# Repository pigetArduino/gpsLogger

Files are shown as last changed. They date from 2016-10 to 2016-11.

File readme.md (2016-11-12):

GPS Logger
----------

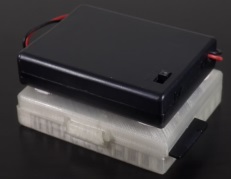
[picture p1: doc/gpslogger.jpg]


[Version française / French version](https://github.com/pigetArduino/gpsLogger/blob/master/readme.fr.md)

Record gps coordinate in a csv file on an Micro card every 15 seconds (DAYHOURMINUTESSECOND.csv)   
[Example file](https://github.com/pigetArduino/gpsLogger/blob/master/doc/example.csv)

# Download link
http://gps.madnerd.org

# Videos / Instructables
* How to build it : https://www.youtube.com/watch?v=gYxDJqSLVxQ
* How to use it : https://www.youtube.com/watch?v=96iCh5vVnsw
* Instructables : http://www.instructables.com/id/Simple-GPS-Logger/

# How to convert the track

## Gpsies.com
* Go to http://gpsies.com
* Click on Create a track
* Import the csv file
* Or click on convert to get a gpx track file

## Viking
* Download it here : https://sourceforge.net/projects/viking/
* Go to file
* Retrieve
* Import file with GPS Babel
* Choose (at the end of the list) : universal csv with field structure in first line
* Add a map in layer
* Use Open Street Map (Mapnick) or Bing Aerial

# Buzzer
The buzzer will tell you if there is any issues with the gps/ micro sdcard
* Heavy sound : Wiring issues or no microsd 
* Soft repetitive sound : GPS is calibrating (can take up to 5 minutes)
* Melody : GPS is online
* Soft and short sound : GPS coordinates saved to sd  

# Components
Use theses keyword to find the components
* Gps module ublox Aircraft model mwc: 8€
* Micro sd card 2go (w/ micro sd card adapter): 4€
* Batteries holder 4AAA on/off : 1€ 
* Arduino mini pro 3.3V : 1,50€
* Passive buzzer 3v:  1€  
* Total : 15.50€   

We are using a micro sd card adapter as a micro sdcard reader but you can also use a micro sd card reader module for this.

# Tools
* FTDI basic breakout usb ttl 3.3 : 6.23€
* Cable 30awg  8-color: 5.37€
 
# Software needed:
  * Arduino (Programmation): http://arduino.madnerd.org
  * Cura (3D printing): https://ultimaker.com/en/products/cura-software

# 3D models
[See 3D models](https://github.com/pigetArduino/gpsLogger/blob/master/3D/)
```
Tested on Ultimaker 2 GO with PLA
To improve solidity print A in solid
A Infill: Solid
B Infill: Light
```
* Author : Olivier Sarrailh   

# Wiring:
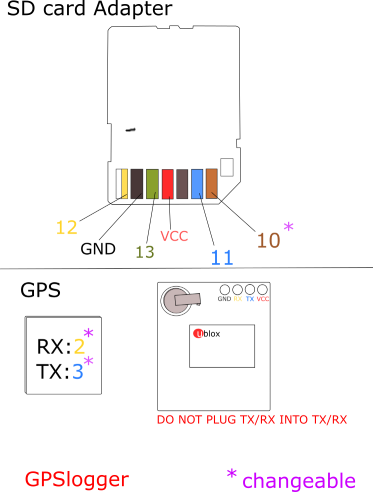
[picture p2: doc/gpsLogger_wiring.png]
Wiring GPS

##  Micro SD card Adapter
```
1 --> Not connected
2 --> 12
3 --> GND
4 --> 13
5 --> VCC
6 --> GND
7 --> 11
8 --> 10 (Chip select)
```
##  GPS
```
RX --> 2
TX --> 3

```
## Buzzer
```
+ ---> 9
```

# Batttery pack placement
As stated by bwh13 on instructables : 
You should avoid obstructing the antenna with the battery pack
```
Nice project.
Moving forward, consider placing your battery pack beneath your GPS module. The antenna works best with an unobstructed view of the sky
```

## Libraries
TinyGPS++ library : https://github.com/mikalhart/TinyGPSPlus

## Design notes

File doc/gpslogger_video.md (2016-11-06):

# Introduction

*   Today I will show you my gps Logger
*   This gps can be made for under 20 euros
*   And it pretty straightforward to use as there is only an on/off switch. 
*   When you power it up, the GPS will start to search for satellites for about 5 minutes
*   And then every 15gseconds, it will write your current position on a micro sd card
*   If you want to see how we made this GPS.
*   Watch the video in the description.
*   Let’s see what’s inside this case.

# Components

*   We have an arduino mini pro 3V
*   A microsd adapter
*   A gps with his antenna
*   A buzzer which will warm us if something doesn’t works
*   And finally a battery holder to power everything

Once you recorded a track on your microsd card you can display it on your computer using the website : gpsies.com or the software: viking

# Retrieve the GPS track

*   As an example we are going to use the track available in the documentation named : example.csv

## Text editor

*   First, Let’s open it with a text editor
*   As you can see the file is easy to understand and can be easily parse by others softwares
*   Let's see our track on a map and convert it as a gpx.

## Gpsies.com

*   The easiest way to do this, is to use the website gpsies.com
*   We just have to create a track and then import our file example.csv
*   We, now can see our gps track on a map
*   If you want to convert your track to read it with any GPS
*   Go to convert, browse, open your track
*   Click on Convert , and this will automatically download the gpx file

## Viking

*   You can also convert your track using the free software viking
*   Go to file, retrieve, import file with gps babel
*   Then open the csv file on the SD card of your GPSLogger
*   Finally go at the end of the list, to universal csv with field structure in first line
*   And press OK
*   This will display your track
*   You still need to add a map
*   We are going to use openstreetmap
*   You can use other maps like bing Aerial,
*   or even photos, scanned map…
*   The map will be download on your computer, so you won’t need a internet connection afterwhile
*   Click on OK
*   And that's it

# Ending

*   As always, all the link are in the description
*   Feel free to ask questions in the comments
*   And subscribe if you don’t want to miss my next projects!
*   Next time, we will see how to make a synth with a Raspberry Pi
*   Using samplerbox
*   I’ll try to make it as easy as possible
*   And show you my mod to use it as a drum machine
*   See you soon!

# Demo

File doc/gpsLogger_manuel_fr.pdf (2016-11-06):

# pigetArduino/gpsLogger

github.com/pigetArduino/gpsLogger/blob/master/readme.fr.md

pigetArduino

### Traceur GPS (GPS Logger)

Enregistre les coordonées GPS dans un fichier csv sur une carte micro sd toutes les 15 seconds (JOURHEUREMINUTESSECONDES.CSV) Fichier d'exemple (https://github.com/pigetArduino/gpsLogger/blob/master/doc/example.csv)

## Télécharger

http://gps.madnerd.org

## Comment convertir le parcours

### Gpsies.com

Aller sur http://gpsies.com
Cliquer sur Créer un parcours
Importer votre fichier csv
Ou Cliquer sur convertir pour avoir un fichier gpx

### Viking

Télécharger Viking ici : https://sourceforge.net/projects/viking/ Aller sur fichier
Récupérer
Import file with GPS Babel
Choosisez (à la fin de la liste) : Import with gps babel Ajouter une map dans couches
Utilisez Open Street Map (Mapnick) ou Bing Aerial

## Sound du Buzzer

Son fort: Erreur de câblage ou carte SD absente
Son calme, court et répétitif : Le GPS est en calibration (cela peut prendre jusqu'à 5 minutes) Mélodie : Le GPS est fonctionnel
Son calme, court , toutes les 15 secondes: Coordonées sauvegardées

## Composants

Utilisez ses mots-clés pour chercher les composants:

Gps module ublox Aircraft model mwc: 8€ Micro sd card 2go : 4€
Batteries holder 4AAA on/off : 1€ Arduino mini pro 3.3V : 1,50€
Passive buzzer 3v: 1€
Total : 15.50€

## Outils

FTDI basic breakout usb ttl 3.3 : 6.23€ Cable 30awg 8-color: 5.37€

## Logiciels:

Arduino (Programmation): http://arduino.madnerd.org
Cura (3D printing): https://ultimaker.com/en/products/cura-software

## Modèles 3D

Voir les modèles 3D (https://github.com/pigetArduino/gpsLogger/blob/master/3D/)

Testé sur une ultimaker 2 GO avec du PLA
Pour améliorer la solidité imprimer la partie A en solide.
A Infill: Solid
B Infill: Dense

Auteur : Olivier Sarrailh

## Câblage:

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
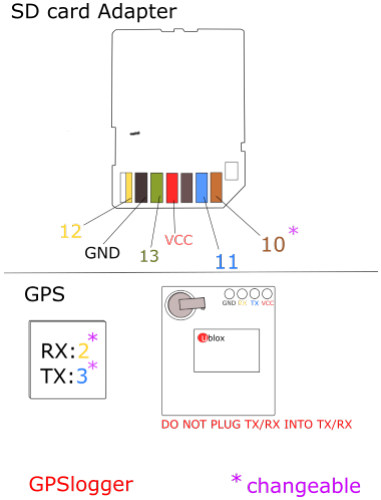
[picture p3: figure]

9 | 3/4

### Bibliothèques

TinyGPS++ library : https://github.com/mikalhart/TinyGPSPlus

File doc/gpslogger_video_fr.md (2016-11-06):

# Présentation

- Aujourd'hui on va voir un traceur GPS  
- Ce traceur GPS peut être fabriqué pour moins de 20 euros   
- Et il fonctionne vraiment simplement.   
- Il y a un bouton on/off, lorsque l'on appuie sur ON    
- Le gps va s'activer et une fois qu'il aura trouver les satellites
- Il va écrire toutes les 15 secondes sur une carte micro sd, votre position.
- Si vous voulez voir un peu comment ce GPS a été fabriqué.
- J'ai fait une vidéo très rapide où on voit toutes les étapes de fabrication 
de ce gps
- Allons voir un peu les composants à l'intérieur de ce boitier.   

# Composants
- A l'intérieur de notre boitier, 
- on a un arduino mini pro 3V
- Un adaptateur de microsd
- un gps ainsi que son antenne
- Et un buzzer qui va nous permettre de savoir si le gps fonctionne correctement
- Evidemment nous avons aussi un boitier de piles en bas qui va nous permettre d'alimenter notre arduino

Maintenant nous allons voir comment utiliser les données de notre GPS sur le site gpsies.com et directement avec le logiciel viking

# Récupérer le parcours GPS
* Comme exemple, nous allons prendre le fichier qui est fourni avec la documentation

## Editeur de texte
* example.csv, nous allons l'ouvrir avec un éditeur de texte standard
* Comme vous pouvez voir c'est un fichier qui est complètement lisible même avec le programme le plus basique possible
* Qu'est que'on va faire de ce fichier ?

## Gpsies.com
* Le plus simple si vous voulez le convertir où l'afficher c'est d'utiliser le site gpsies.com
* Sur ce site , on peut créer un parcours sur lequel on va importer notre fichier example.csv
* Et voilà! Nous avons notre tracé GPS sur une magnifique carte
* Alors, Si vous voulez juste convertir le fichier de façon à ce qu'il soit lisible par un GPS
* Il faut aller sur convertir, parcourir, ouvrir le fichier de la carte SD de votre GPS
* Convertir , et il vous donnera directement un fichier GPX

### Viking
* Si vous ne voulez pas passer par un site, vous pouvez utiliser le logiciel libre viking
* Pour cela, il faut aller dans fichier, récupérer, import file with gps babel
* Vous ouvrez votre fichier csv de la carte SD du GPSLogger
* Et après vous aller toute en bas à universal csv with field structure in first line
* Et vous faites valider
* Ca fait afficher toutes les points que le gps a récupéré
* Par défaut Viking n'utilise aucune carte
* Nous allons utiliser openstreetmap pour notre carte
* Vous pouvez utiliser d'autres cartes, voir même utiliser des images
* Vue que le logiciel est vraiment malléable là-dessus.
* Une fois que vous aurez télécharger la carte , vous n'aurez plus besoin d'internet normalement
* pour exploiter vos données.
* Reste plus qu'à valider
* Et voilà! Nous avons une jolie carte.

# Fin
* Comme d'habitude les liens sont dans la description
* N'hésitez pas à poster un commentaire si vous avez des questions
* Abonnez vous pour ne pas louper les prochaines vidéos
* La prochaine fois nous verrons comment faire un synthé avec un Raspberry Pi
* Non seulement on va faire un synthé mais aussi une boite à rythme
* Tout ça sans utiliser la moindre soudure
* Et sans passer par le terminal
* Juste en copier des trucs sur une carte SD 
* Et sur une clé USB.
* Allez à la prochaine

# Démonstration

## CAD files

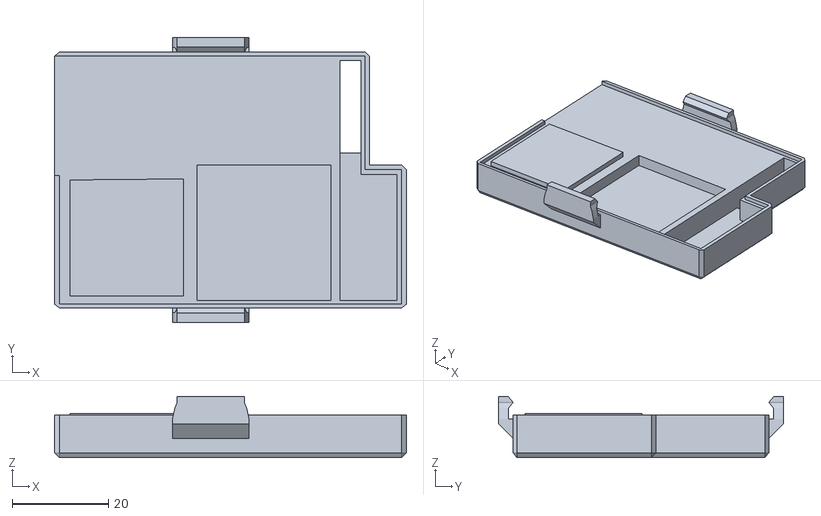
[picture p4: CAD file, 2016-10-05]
3D/gpslogger_B.stl
73.3 x 59.3 x 12.7

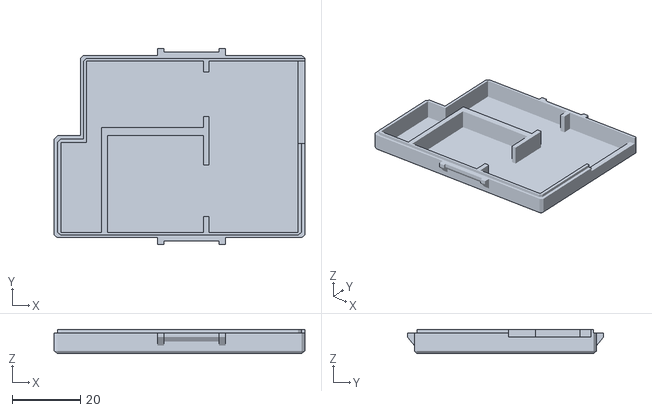
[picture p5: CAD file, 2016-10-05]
3D/gpslogger_A.stl
73.3 x 57.3 x 7.05

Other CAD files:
3D/gpslogger.blend

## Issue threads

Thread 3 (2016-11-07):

How do you get the recorded data off of the device if SD card is soldered?

slavik0329, 2016-11-07:
How do you get the recorded data off of the device if SD card is soldered?

maditnerd, 2016-11-09:
I realize I wasn't really clear about it, I solder a micro-sd card adapter not an sdcard.
I should probably update the doc to reflect this better.

slavik0329, 2016-11-11:
@maditnerd Yea, there is nothing in the docs at all about this. Thank you !

Closed 2016-11-11.

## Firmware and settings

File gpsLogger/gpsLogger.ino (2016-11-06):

/*
  Author: MadNerd.org
  Date:10/05/2016
  Licence: Mit

  Log speed/altitude/gps coordinate in a universal csv file (DAYHOURMINUTESSECOND.csv)
  You can convert .csv to a gpx with http://www.gpsies.com/convert.do
  You can also display it on viking https://sourceforge.net/projects/viking/
  You can reuse theses values in any spreedsheet software (LibreOffice/Excel...)

  Buzzer sound
  -- Heavy sound : GPS/SD card fatal error
  -- Soft repetitive sound : GPS is calibrating
  -- Soft and short sound : GPS coordinates saved to sd

  Components:
    Ublox GPS module (or compatible with tinygps++)
    Micro SD to SD card Adapter
    A buzzer
    An Arduino Pro Mini 3V
    Batteries

  Tools:
  ftdi 3V/5V programmer

  Wiring:
  SD card
  1 --> X
  2 --> 12
  3 --> GND
  4 --> 13
  5 --> VCC
  6 --> GND
  7 --> 11
  8 --> 10 (Chip select)

  GPS
  RX --> 2
  TX --> 3

  Buzzer --> 9

  You will need
    TinyGPS++ library

  Previous Readme
  This example uses software serial and the TinyGPS++ library by Mikal Hart
  Based on TinyGPSPlus/DeviceExample.ino by Mikal Hart
*/

/* Dependencies */
// GPS
#include <TinyGPS++.h>
#include <SoftwareSerial.h>
// SD
#include <SPI.h>
#include <SD.h>


/*
  Settings
*/
//Seconds between save
const int gps_interval = 15 * 1000;

const int timezone = 0;
//France +1
//England +0
//etc...

/* GPS */

//GPS TX/RX (don't use default TX/RX)
const int RXPin = 2;
const int TXPin = 3;

// Ublox run at 9600
const int GPSBaud = 9600;

//SD
const int chipSelect = 10;

//Buzzer
const int buzzer = 9;


bool locationOK = false; //Is GPS connected ?
bool sdOK = true; //Is SD card detected ?

String string_filename;
char* filename;

/* Formatted Date and Time */
String s_day;
String s_month;
String s_year;
String s_hour;
String s_minute;
String s_second;

// Create a TinyGPS++ object called "gps"
TinyGPSPlus gps;

// Create a software serial port called "gpsSerial"
// We can't use TX/RX pins if we don't want to lose the ability to debug/upload code
SoftwareSerial gpsSerial(TXPin, RXPin);

void setup() {
  // Start Serial debug
  Serial.begin(9600);

  buzz(800, 200);

  // Start GPS Serial
  gpsSerial.begin(GPSBaud);

  // Start SD Card
  if (!SD.begin(chipSelect)) {
    Serial.println("SD : ERROR");
    sdOK = false;
    // don't do anything more:
    return;
  }
  Serial.println("SD : OK");
}

void loop() {
  // When GPS send coordinates
  while (gpsSerial.available() > 0)
    if (gps.encode(gpsSerial.read())){
      formatData(); //Format data
      displayInfo(); //Display debug
      saveToSD(); //Save in SDCard
      
    }

  // Check if GPS is OK
  if (millis() > 5000 && gps.charsProcessed() < 10) {
  // If 5000 milliseconds pass and there are no characters coming in
  // over the software serial port.
    Serial.println(F("GPS : ERROR"));
    buzz(700, 2000); //GPS error panic
  }

}

//Make sound using a buzzer/speaker
void buzz(int freq, int waitTime) {
  tone(buzzer, freq);
  delay(waitTime);
  noTone(buzzer);
  delay(waitTime);
}


//SD : Write Header for CSV file
void writeHeaders() {
  Serial.println("Writing header");
  Serial.println(filename);
  File gpsFile = SD.open(filename, FILE_WRITE);
  if (gpsFile) {
    gpsFile.println("Latitude,Longitude,Alt,Date,Time,Speed");
  } else {
    Serial.println("SD : ERROR WRITING");
  }
  gpsFile.close();
}


//Format data
void formatData(){
   /* Format Date */
  // Year
  s_year = gps.date.year();

  // Day
  if (gps.date.day() < 10) {
    s_day = "0" + String(gps.date.day());
  } else {
    s_day = String(gps.date.day());
  }

  // Month
  if (gps.date.month() < 10) {
    s_month = "0" + String(gps.date.month());
  } else {
    s_month = String(gps.date.month());
  }

  // Hour

  // UTC Adjustement
  int adj_hour = gps.time.hour() + timezone;

  if (adj_hour < 10) {
    s_hour = "0" + String(adj_hour);
  } else {
    s_hour = String(adj_hour);
  }

  // Minutes
  if (gps.time.minute() < 10) {
    s_minute = "0" + String(gps.time.minute());
  } else {
    s_minute = String(gps.time.minute());
  }

  // Seconds
  if (gps.time.second() < 10) {
    s_second = "0" + String(gps.time.second());
  } else {
    s_second = String(gps.time.second());
  }
}

/* Display debug information */
void displayInfo() {
  //Date
  Serial.print(s_day);
  Serial.print(F("/"));
  Serial.print(s_month);
  Serial.print(F("/"));
  Serial.print(s_year);
  Serial.print(" ");

  //Time
  Serial.print(s_hour);
  Serial.print(F(":"));
  Serial.print(s_minute);
  Serial.print(F(":"));
  Serial.print(s_second);

  //Lat / Long / Altitude / Speed
  Serial.print(F(","));
  Serial.print(gps.location.lat(), 6);
  Serial.print(F(","));
  Serial.print(gps.location.lng(), 6);
  Serial.print(F(","));
  Serial.print(gps.altitude.meters(), 6);
  Serial.print(F(","));
  Serial.print(gps.speed.kmph());
  Serial.println();
}

void saveToSD() {
  //Check if SD card works or stop
  if (sdOK) {
    /* Create file when gps found a position */
    //If GPS didn't find position (latitude = 0)
    if (! locationOK) {
      if (gps.location.lat() != 0)
      {
        //Buzz
        buzz(600, 1000);

        //Create filename
        string_filename = s_day + s_hour + s_minute + s_second + ".csv";

        //Convert filename string to char
        unsigned int bufSize = string_filename.length() + 1; //String length + null terminator
        filename = new char[bufSize];
        string_filename.toCharArray(filename, bufSize);

        //GPS found
        locationOK = true;

        //Display filename
        Serial.println("FILENAME");
        Serial.println(filename);

        //Write first line of CSV
        writeHeaders();

      }
    } else {
      //Buzz until GPS is OK
      buzz(5, 5);
    }

    //Append position to file each 15 minutes (by default)
    if (locationOK) {
      //Check if GPS hasn't lost position (it will keep last position but reset date)
      if (gps.date.year() != 2000) {

        //We make the arduino wait
        delay(gps_interval);

        //Buzz to tell the user data is written
        buzz(200, 100);
        Serial.println("APPEND");

        //Open file
        File gpsFile = SD.open(filename, FILE_WRITE);

        if (gpsFile) {
          //Latitude / Longitude
          gpsFile.print(gps.location.lat(), 6);
          gpsFile.print(F(","));
          gpsFile.print(gps.location.lng(), 6);

          //Altitude (meters) (doesn't seems to work)
          gpsFile.print(F(","));
          gpsFile.print(gps.altitude.meters(), 6);

          //Date 2003/06/29
          gpsFile.print(F(","));
          gpsFile.print(s_year);
          gpsFile.print(F("/"));
          gpsFile.print(s_month);
          gpsFile.print(F("/"));
          gpsFile.print(s_day);

          //Time 09:00:00
          gpsFile.print(",");
          gpsFile.print(s_hour);
          gpsFile.print(F(":"));
          gpsFile.print(s_minute);
          gpsFile.print(F(":"));
          gpsFile.print(s_second);

          //Speed (km/h)
          gpsFile.print(F(","));
          gpsFile.print(gps.speed.kmph());
          gpsFile.println();
        } else {
          Serial.println("SD : ERROR WRITING");
        }
        gpsFile.close(); //Close file
      }
    } else {
      buzz(5, 5); //Searching satellite
    }
  } else {
    buzz(600, 1000); // No SD card panic
  }
}

/*

  +-------------------------------+     +----------------------------------+
  |                               |     |           +--+ +--+ +--+ +--+    |
  |                               |     |   ---     |  | |  | |  | |  |    |
  |                               |     |  +   |    +--+ +--+ +--+ +--+    |
  |       SD CARD                 |     |   ---                            |
  |                               |     |           GND   RX  TX   VCC     |
  |                               |     |                                  |
  |                               |     |            +     +   +    +      |
  |                               |     |            |     |   |    |      |
  |                               |     |            |     |   |    |      |
  |                               |     |            v     v   v    v      |
  |                               |     |           GND    2   3   VCC     |
  |                               |     |                                  |
  |                               |     |          +---------------+       |
  +-                               ++    |          |               |       |
  |                                 |    |          | Ublox GPS     |       |
  |                                ++    |          |               |       |
  |                            +-+ |     |          |               |       |
  +-                           |-| |     |          +---------------+       |
  |                           +-+ |     |                                  |
  | +---+ +-+ +-+ +-+ +-+ +-+     |     |                                  |
  | |-| | | | | | | | | | | |     |     |                                  |
  | +---+ +-+ +-+ +-+ +-+ +-+     |     |                                  |
  +   12 GND  13  VCC 11  10     ++     |                                  |
  +-----------------------------+       +----------------------------------+

*/

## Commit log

2016-09-07 First autocommit by pigetBot
    [5x7i.blend, 5x7iBASE.stl, 5x7iTOP.stl]
2016-10-05 Update doc/Update 3D models
    [5x7i.blend, 5x7iBASE.stl, 5x7iTOP.stl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]
2016-10-05 Typo in rx/tx pin in sketch
2016-11-06 Set timezone to 0 Try something to fix altitude
    [gpsLogger.ino]
